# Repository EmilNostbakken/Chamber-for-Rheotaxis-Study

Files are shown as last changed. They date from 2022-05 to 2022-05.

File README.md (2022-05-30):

# Chamber-for-Rheotaxis-Study

Chamber-for-Rheotaxis-Study consists of open software and hardware designed for studying rheotaxis for small swimming animals. This system was designed for experiments with the Ciona Intestinalis larvae.

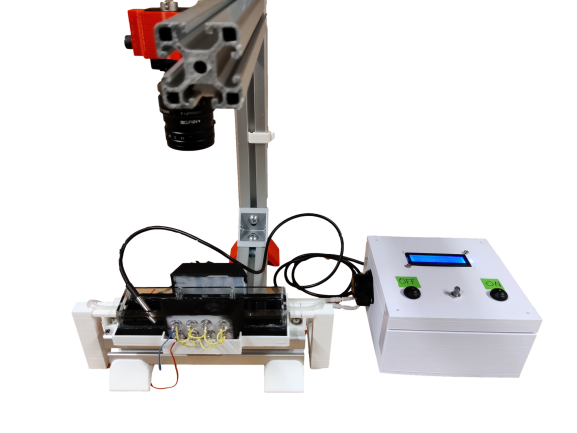
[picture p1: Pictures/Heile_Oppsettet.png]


## Hardware

The Hardware folder contains all STL files for 3D-printing, electronic components list, schematic and files for laser cutting.

## Software
The MicroControllerCode folder contains the arduino code used for this project

## User Guide

Before you start, make sure the system is clean, especially the meshes. You can clean the meshes with ethanol but be careful to not get ethanol on the glue. The chamber should be cleaned with water and soap because the glue used on the chamber could be damaged with ethanol. Ensure that the IR-light components are correctly positioned.

__Step 1: Setup__

Make sure the tubes are in their respective tracks and that they are properly inside each hole of both sides of the chamber. Turn on the PC and check if the camera is in position and working. This is how the setup should look like before starting:
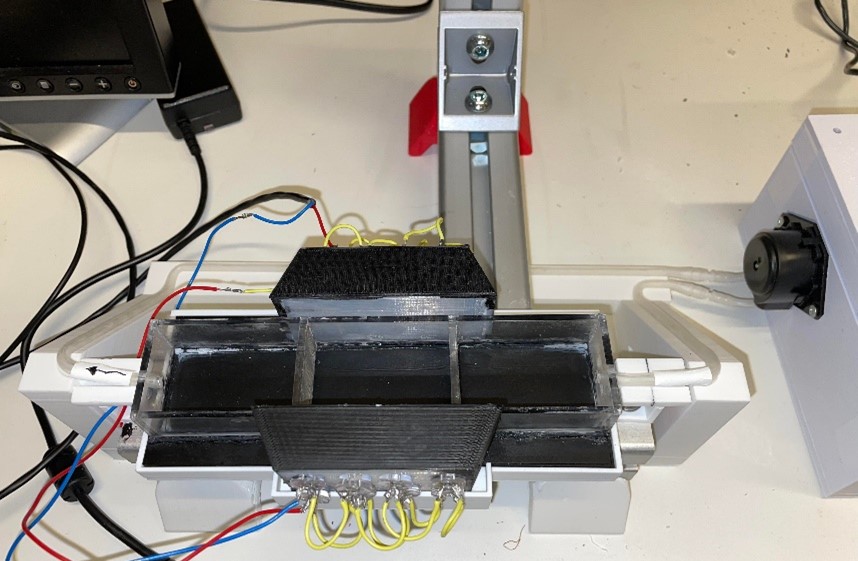
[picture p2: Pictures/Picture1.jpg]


__Step 2: Power__

There are three components that needs to be plugged into a 230V AC power socket. Two power plugs for the electrical box and one for the IR-lighting. The two power plugs from the box are for the Arduino and H-bridge.
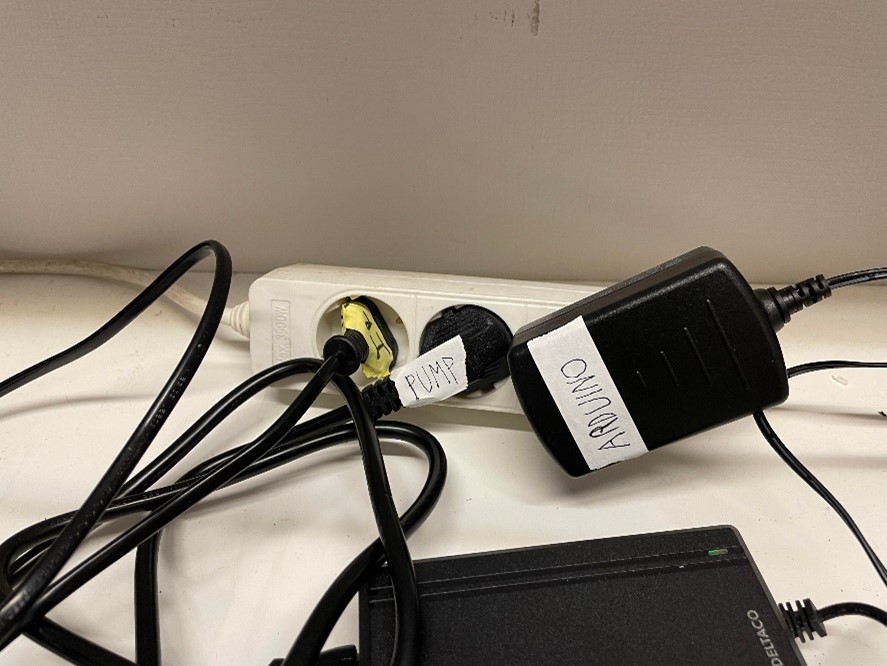
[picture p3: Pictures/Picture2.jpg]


__Step 3: Prepare for animals__

Fill the chamber with cooled sea water (about 15°C) until the water is above the tube level. Press the “ON” button and look at the camera preview if the waterflow is desirable. You can turn the potentiometer for desired pump effect. When there’s no air in the tubes, press the “OFF” button and add the animals to the observation section of the chamber (between the meshes in the middle).


__Step 4: Collecting video__

When satisfied with amount of animals and camera quality you start the recording on the PC. Approximately 1-2 seconds after you begin recording, start the pump using the “ON” button. When you are satisfied with the recording length you press the “OFF” button, then stop recording.

__User Guide Video:__  https://youtu.be/hHmM167tq60

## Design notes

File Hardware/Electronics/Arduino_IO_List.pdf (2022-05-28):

ARDUINO I/O LIST
Arduino Port | Component side | Description
A0 | Potentiometer
A4 | LCD:SDA | LCD = liquid crystal display module
A5 | LCD:SCL
5V | PCB:L0 | Lower side of PCB
GND | PCB:L1 | Lower side of PCB
5V | LCD:VCC
GND | LCD:GND
GND | H-Bridge:GND | L298N H-Bridge
D2 | H-Bridge:IN1
D3 | PCB:S0 | Left side of PCB
D4 | PCB:U8 | Upper side of PCB
D5 | H-Bridge:ENA
D6 | PCB:U5 | Upper side of PCB

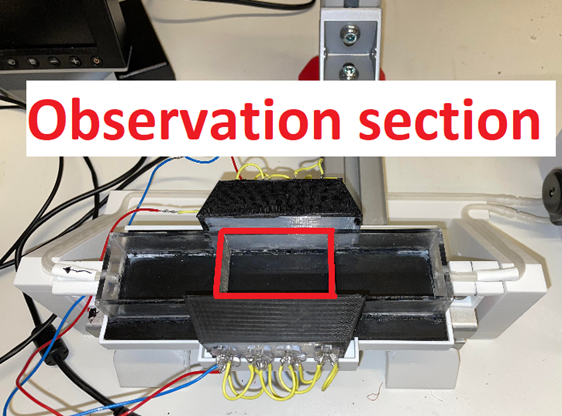
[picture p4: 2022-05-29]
Pictures/Picture3.png

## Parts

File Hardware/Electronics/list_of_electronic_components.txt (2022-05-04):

Arduino UNO
LCD-Display
LCM1602 IIC module
12V Power Supply
12V DC Pump
Clear Plastic Tubing
L298N H-Bridge
2X Pushbuttons
Potentiometer
Wires
DS18B20 Temperature Sensor
PCB Board
2X 220 Ohm resistor
4.7 kOhm resistor
5X 2-pin screw terminals

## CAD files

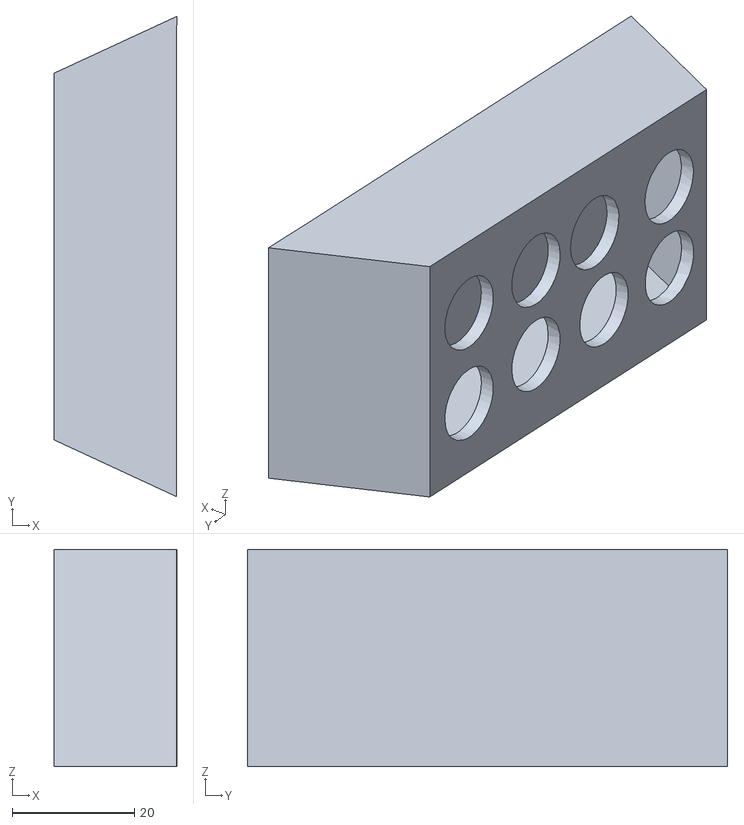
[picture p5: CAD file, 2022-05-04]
Hardware/3D_Print_Files/IR-LED_Holder.stl
20.1 x 78.6 x 35.5

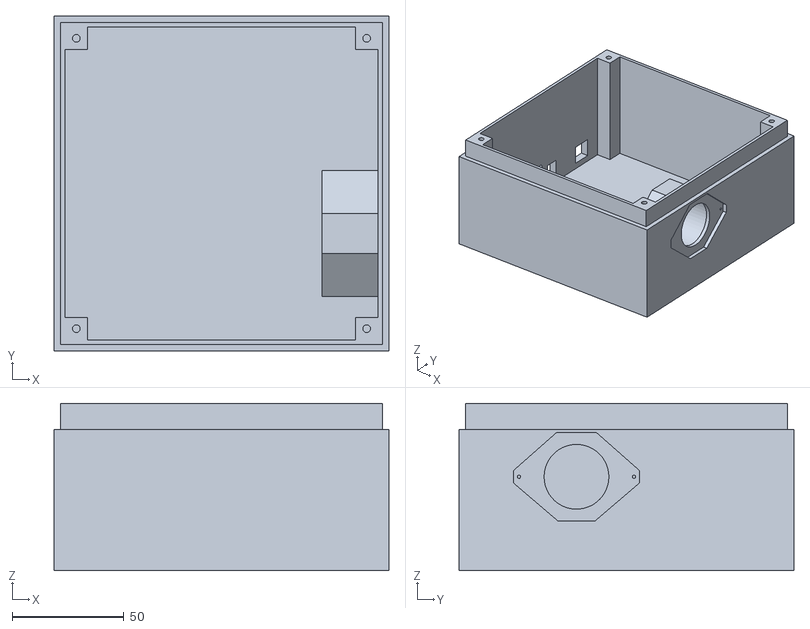
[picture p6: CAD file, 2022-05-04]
Hardware/3D_Print_Files/Box_bottom.stl
150.0 x 150.0 x 75.0

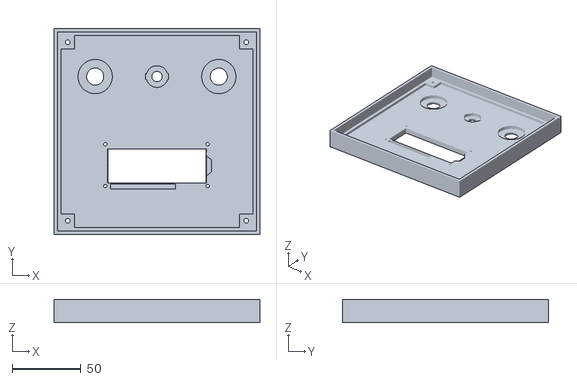
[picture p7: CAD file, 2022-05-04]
Hardware/3D_Print_Files/Box_top.stl
150.0 x 150.0 x 17.0

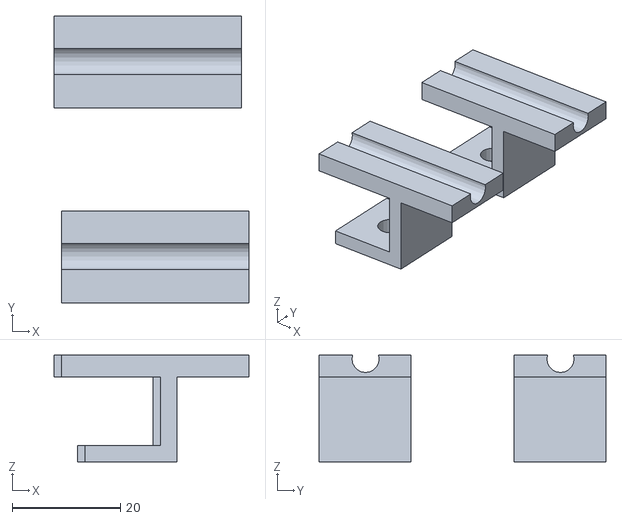
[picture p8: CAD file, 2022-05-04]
Hardware/3D_Print_Files/TubingEntrance.stl
36.0 x 53.0 x 19.7

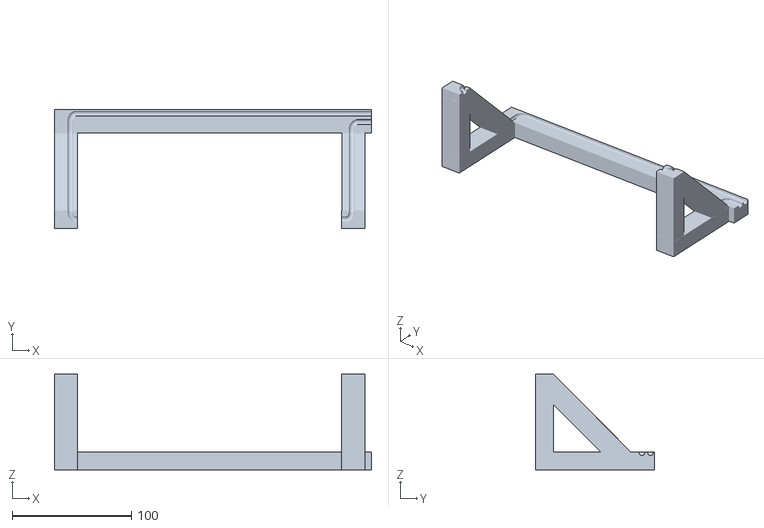
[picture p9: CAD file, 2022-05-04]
Hardware/3D_Print_Files/TubingHolder.stl
265.4 x 100.0 x 80.1

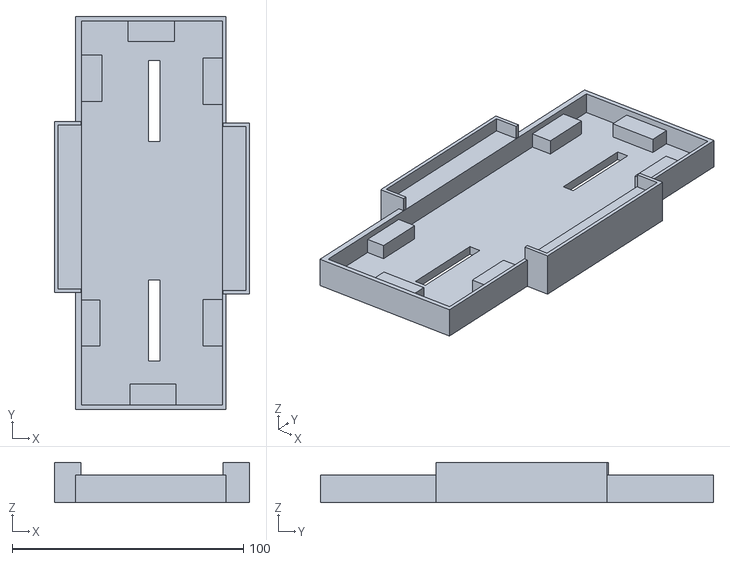
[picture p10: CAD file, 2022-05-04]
Hardware/3D_Print_Files/ChamberFrame.stl
84.3 x 170.0 x 17.5

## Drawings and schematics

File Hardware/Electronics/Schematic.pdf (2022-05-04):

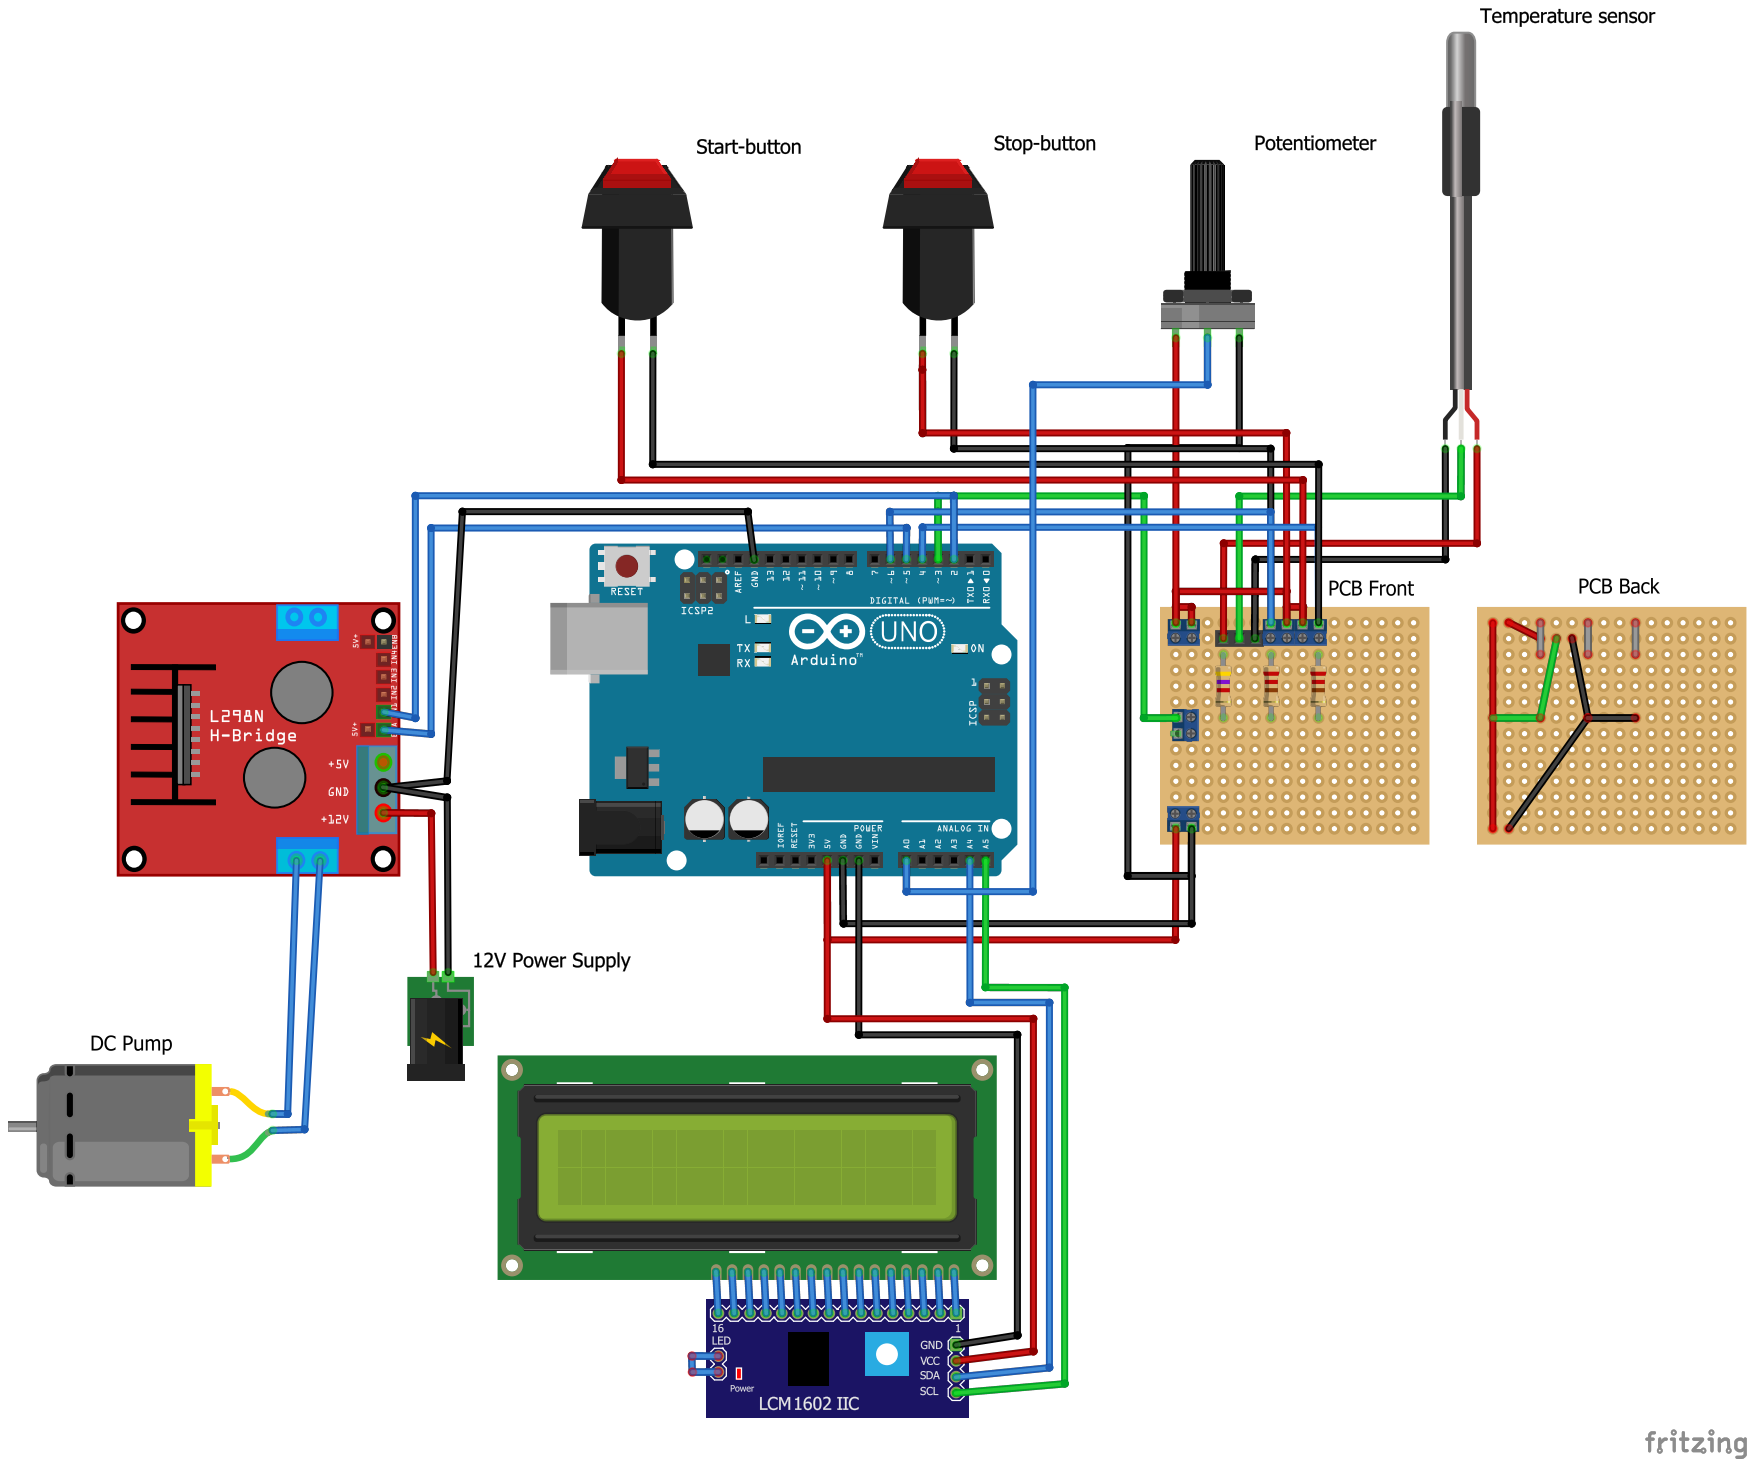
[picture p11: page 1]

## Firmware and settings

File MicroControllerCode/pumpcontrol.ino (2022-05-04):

#include <LiquidCrystal_I2C.h>
#include <OneWire.h>
#include <DallasTemperature.h>

// Data wire is plugged into pin 3 on the Arduino
#define ONE_WIRE_BUS 3

// Setup a oneWire instance to communicate with any OneWire devices
OneWire oneWire(ONE_WIRE_BUS);

// Pass our oneWire reference to Dallas Temperature.
DallasTemperature sensors(&oneWire);

LiquidCrystal_I2C lcd(0x27, 16, 2);
const int buttonPin1 = 4; // Starts pump flow
const int buttonPin2 = 6; // Stops pump flow
// Establish pins for motor driver
const int motor1pin1 = 2;
// Establish pin used for user to control pump speed
const int analogInPin = A0;
// Establish output pin of user's pump speed input
const int analogOutPin = 5;
// Initialize values from user input
int sensorValue;
int outputValue;
int voltpercent;
// Initialize button states
int buttonState1 = 0;
int buttonState2 = 0;
int lastButtonState1 = 0;
int lastButtonState2 = 0;

void setup() {

  //Start up the library
  sensors.begin();
  sensors.requestTemperatures(); //Send the command to get temperature readings

  pinMode(motor1pin1, OUTPUT);
  pinMode(analogOutPin, OUTPUT);
  pinMode(buttonPin1, INPUT);
  pinMode(buttonPin2, INPUT);

  sensorValue = 0;
  outputValue = 0;
  voltpercent = 0;

  //Initializing lcd
  lcd.init();
  lcd.backlight();
  Serial.begin(9600);
  lcd.setCursor(0, 0);
  lcd.print("Off");
  lcd.setCursor(6, 0);
  lcd.print(sensors.getTempCByIndex(0));
  lcd.setCursor(11, 0);
  lcd.print("C");
}

void loop() {
  sensorValue = analogRead(analogInPin); // Reads voltage from output of potentiometer
  outputValue = map(sensorValue, 0, 1023, 0, 255); // Maps range of potentiometer to range of possible motor speeds
  voltpercent = map(outputValue, 0, 255, 0, 100); // Maps range of speeds to a percentage value to be printed for user feedback
  //Controlling speed (0 = off and 255 = max speed):
  analogWrite(analogOutPin, outputValue); //ENA pin

  // Read the states of all the buttons
  buttonState1 = digitalRead(buttonPin1);
  buttonState2 = digitalRead(buttonPin2);

  // Update the speed percent value displayed
  lcd.setCursor(6, 1);
  if (voltpercent == 100) {
    lcd.print(voltpercent);
    lcd.print("%");
  }
  else if (voltpercent < 100 && voltpercent >= 10) {
    lcd.print(" ");
    lcd.print(voltpercent);
    lcd.print("%");
  }
  else if (voltpercent < 10) {
    lcd.print("  ");
    lcd.print(voltpercent);
    lcd.print("%");
  }

  // The next if statements determine if each button has been pressed
  // button1: Sets motor1pin1 to high which starts pump flow
  if (buttonState1 != lastButtonState1) {
    if (buttonState1 == HIGH) {
      digitalWrite(motor1pin1, HIGH);
      // Displays pump state "On"
      lcd.setCursor(0, 0);
      lcd.print("On ");
    }
  }
  // button2: Sets motor1pin1 to low which turns pump off
  if (buttonState2 != lastButtonState2) {
    if (buttonState2 == HIGH) {
      digitalWrite(motor1pin1, LOW);
      // Displays pump state "Off"
      lcd.setCursor(0, 0);
      lcd.print("Off");
      sensors.requestTemperatures();
      lcd.setCursor(6, 0);
      lcd.print(sensors.getTempCByIndex(0));
      lcd.setCursor(11, 0);
      lcd.print("C");
    }
  }
  // Update button states
  lastButtonState1 = buttonState1;
  lastButtonState2 = buttonState2;

}
